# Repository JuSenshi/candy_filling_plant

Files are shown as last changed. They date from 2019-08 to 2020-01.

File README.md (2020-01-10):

# candy_filling_plant

# Projektbeschreibung
Das Fließbandsystem mit Abfüllanlage ist ein großer Bestandteil unseres gesamten Schulprojekts, der Automatisierung einer Bonbon - Abfüllanlage inkl. Lieferungslösung. Dieses Teilprojekt stellt den Prozess des Abfüllens der bestellten Bonbonbs bereit. Dies wird durch ein selbstkreiertes Fließband mit einem Schrittmotor, sowie einer Abfülllösung mit 3 Servomotoren erreicht. Desweiteren wird die Bestellung von einem RFID - Chip gelesen. Hierfür benutzen wir unter dem Fließband ein RFID - Lesegerät.

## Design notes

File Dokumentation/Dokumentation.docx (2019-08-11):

# Dokumentation - Bonbon Abfüllanlage

Elektrotechnik

# 1. Bauteil – Liste

## 1.1. Boards

Boardbezeichnung | Beschreibung
Arduino Uno R3 (A1) | Modul Abfüllung | Modul Fließband
Arduino Uno R3 (A2) | Modul Schließen
Motortreiber X113647 (X1) | Treiberplatine für Schrittmotor
RFID Modul MFRC-522 | RFID Modul zum Auslesen von Tags

## 1.2. Sensoren

Sensorbezeichnung | Beschreibung
B1: IR – Detektor (vgl. SFH 213 FA OSO) | IR Fotowiderstand für LS1
B2: IR – Detektor (vgl. SFH 213 FA OSO) | IR Fotowiderstand für LS2

## 1.3. Aktoren

Aktorbezeichnung | Beschreibung
M1: Servomotor SG90 | Modul Abfüllung | Abfüller Farbe Rot
M2: Servomotor SG90 | Modul Abfüllung | Abfüller Farbe Blau
M3: Servomotor SG90 | Modul Abfüllung | Abfüller Farbe Grün
M4: Servomotor SG90 | Modul Schließen | Schließer Oben
M5: Servomotor SG90 | Modul Schließen | Schließer Unten
M6: Schrittmotor 28BYJ-48 | Modul Fließband | Antrieb Fließband
LED1: IR – LED (vgl. IR 333-H0L10 EVL) | LED für Lichtschranke LS1
LED2: IR – LED (vgl. IR 333-H0L10 EVL) | LED für Lichtschranke LS2

## 1.4. Widerstände

Widerstandsbezeichnung | Beschreibung
R1: 220 Ω | 5% | 250mW | Vorwiderstand LED1 (LS1)
R2: 1k Ω | 5% | 250mW | Vorwiderstand B1 (LS1)
R3: 220 Ω | 5% | 250mW | Vorwiderstand LED2 (LS2)
R4: 1k Ω | 5% | 250mW | Vorwiderstand B2 (LS2)

# 2. Pin – Zuordnungen

## 1.1. Arduino A1 → Motortreiber X1

Pin – Arduino A1 | Pin – Motortreiber X1
2 | IN1 (A)
3 | IN2 (B)
4 | IN3 (C)
5 | IN4 (D)
5V | +
GND | -

## 1.2. Arduino A1 → Sensoren | Aktoren

Pin – Arduino A1 | Pin – Sensoren
6 | M1 (gelber Kontakt)
7 | M2 (gelber Kontakt)
8 | M3 (gelber Kontakt)
A0 | A2: A5
A5 | B1: Anode

## 1.3. Arduino A1 → RFID Modul

Pin – Arduino A1 | Pin – RFID Modul
9 | RST
10 | SDA
11 | MOSI
12 | MISO
13 | SCK
3,3V | 3,3V
GND | GND

## 1.4. Arduino A2 → Sonstige

Pin – Arduino A2 | Pin – Sonstige
2 | M4 (gelber Kontakt)
3 | M5 (gelber Kontakt)
A0 | B2: Anode
A5 | A1: A0

# 3. Schaltplan

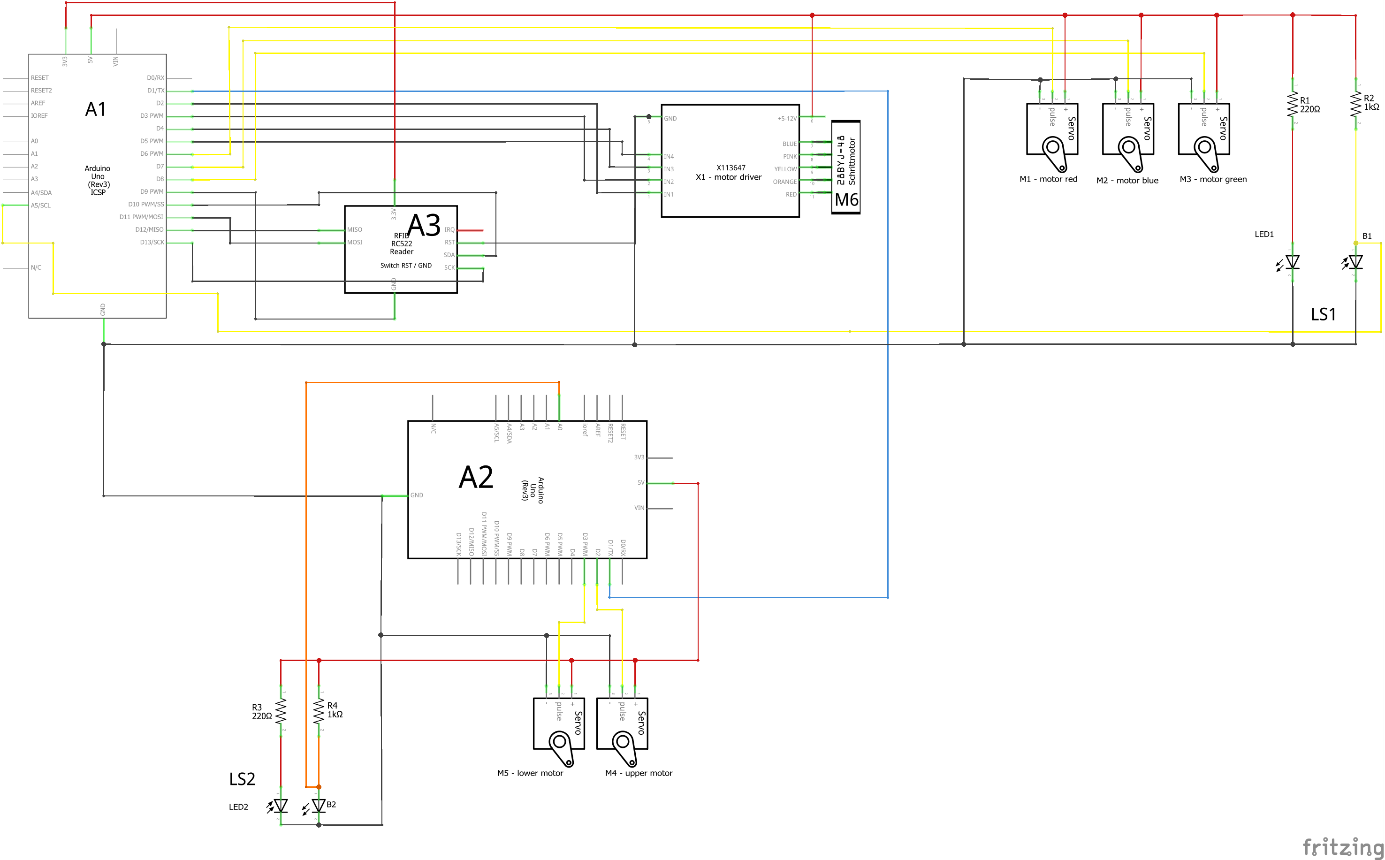
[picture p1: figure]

Bild online aufrufen (https://krieger-blog.de/wp-content/uploads/2019/08/circuit-board-schmetic-1024x636.png)

# 4. Steckplatinenansicht

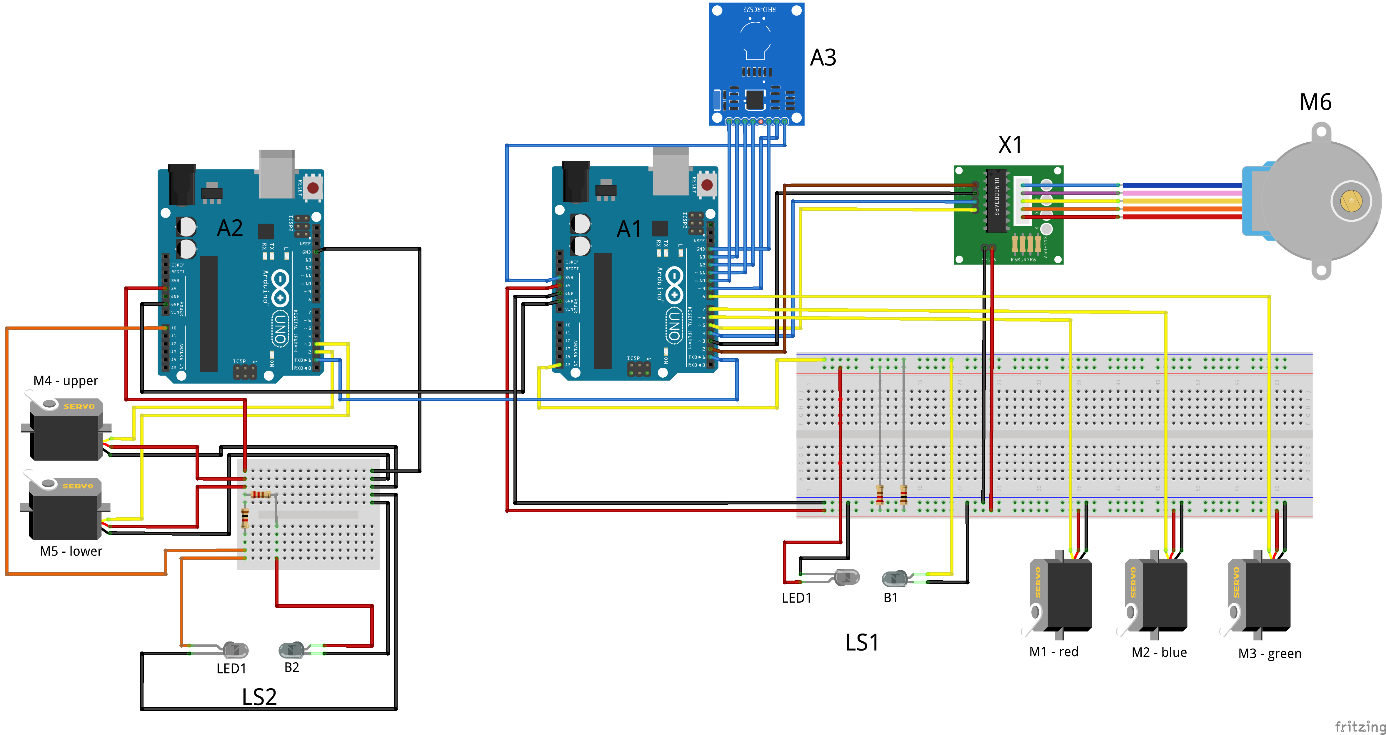
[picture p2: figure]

Bild online aufrufen (https://krieger-blog.de/wp-content/uploads/2019/08/schmetic-1024x543.png)

# 5. Programmcode

Die Programmcodes für beide Arduino Controller sind unter folgendem Link einsehbar und herunterladbar.

Github: Candy Filling Plant (https://github.com/KriegersBlog/candy_filling_plant)

Julian Krieger 11.08.2019 1 von 4

Dokumentation - Bonbon Abfüllanlage

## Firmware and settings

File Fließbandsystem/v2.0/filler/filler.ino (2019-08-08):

#include <SPI.h>                           // Integrates the SPI library for RFID pin support
#include <MFRC522.h>                       // Integrates RFID library for 15.44MHz NFC support
#define SS_PIN 10                          // Pin definition for the RFID library
#define RST_PIN 9                          // Pin definition for the RFID library
MFRC522 mfrc522(SS_PIN, RST_PIN);          // Applys given pins to library
MFRC522::MIFARE_Key key; // access key


uint8_t dataSize = 18;  //Size of all needed data in bytes: commandbyte + addressbyte + 16 data bytes | Anmerkung: Stimmt net
byte trailerBlock = 7;    // the trailer block that holds our security data (used for blocks 4/5/6)


const int L1 = 4; // IN3
const int L2 = 2; // IN1
const int L3 = 5; // IN4
const int L4 = 3; // IN2
const int motor[4] = {0b00000101, 0b00001001, 0b00001010, 0b00000110};
const int box_length = 1600;
const int red_motor = 6;
const int blue_motor = 7;
const int green_motor = 8;

void setup() {
  pinMode(L1, OUTPUT);
  pinMode(L2, OUTPUT);
  pinMode(L3, OUTPUT);
  pinMode(L4, OUTPUT);

  pinMode(red_motor, OUTPUT);
  pinMode(blue_motor, OUTPUT);
  pinMode(green_motor, OUTPUT);
  servo_move(30, red_motor, 100);
  servo_move(50, blue_motor, 100);
  servo_move(0, green_motor, 100);
  SPI.begin();
  mfrc522.PCD_Init();
}

void loop() {
  while (digitalRead(A0) == HIGH) {
    //Nüscht
  }
  if (analogRead(A5) < 900) {
    forward();
  }
  else {
    delay(100);
    mfrc522.PCD_Init();     // Initializes library for the RFID modul
    delay(100);
    
    for (byte i = 0; i < MFRC522::MF_KEY_SIZE; i++) {       //For key size:
      key.keyByte[i] = 0xFF;                                //Type key as OxFF
    }
    if (mfrc522.PICC_IsNewCardPresent()) {
      mfrc522.PICC_ReadCardSerial();
      mfrc522.PCD_Authenticate
      (MFRC522::PICC_CMD_MF_AUTH_KEY_A, trailerBlock, &key, &(mfrc522.uid));

      char chipInput_block4[16];                    //Array for information on block 4
      char chipInput_block5[16];                    //Array for information on block 5

      mfrc522.MIFARE_Read(4, chipInput_block4, &dataSize);
      mfrc522.MIFARE_Read(5, chipInput_block5, &dataSize);
      //Sector 4: 5, 13 | Sector 5: 7

      int bonbons = chipInput_block4[5] - 0x30;   //New int variable that is the size of the wanted bonbonbs
      for (int i = 0; i < bonbons; i++) {         //For number of bonbonbs
        servo_move(0, red_motor, 100);
        delay(100);
        servo_move(30, red_motor, 100);
        delay(100);
      }

      bonbons = chipInput_block4[13] - 0x30;    //Variable is number of wanted bonbons
      for (int i = 0; i < bonbons; i++) {
        servo_move(0, blue_motor, 100);
        delay(100);
        servo_move(50, blue_motor, 100);
        delay(100);
      }

      bonbons = chipInput_block5[7] - 0x30;
      for (int i = 0; i < bonbons; i++) {
        servo_move(50, green_motor, 100);
        delay(100);
        servo_move(0, green_motor, 100);
        delay(100);
      }

      while (analogRead(A5) > 900) {
        forward();
      }
    }
  }
}



void stepper(uint8_t value) {
  digitalWrite(L1, value & 0b00000001);
  digitalWrite(L2, value & 0b00000010);
  digitalWrite(L3, value & 0b00000100);
  digitalWrite(L4, value & 0b00001000);
}

void forward() {
  for (int i = 0; i < 4; i++) {
    stepper(motor[i]);
    delay(2);
  }
}

void backward() {
  for (int x = 3; x >= 0; x--) {
    stepper(motor[x]);
    delay(2);
  }
}


void servo_move(byte angle_degree, uint8_t motor_pin, byte repeater){

    pinMode(motor_pin, OUTPUT);                       //Declares given pin of the servo as output
    int time = (angle_degree/180.0 * 1925) + 425;     //Calculates degree time for a SV-90
    int delaytime = 20000-time;
    for(int i = 0; i<repeater; i++){
      digitalWrite(motor_pin, HIGH);
      delayMicroseconds(time);
      digitalWrite(motor_pin, LOW);
      delayMicroseconds(delaytime);
    }
}

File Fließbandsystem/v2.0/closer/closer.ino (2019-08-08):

/* 
 *  This code is essential for the clsoing mechanism. 
 * Copyright by Julian Krieger, Dennis Domagala, Pascal Gläß
 */


const int top_motor = 2;
const int bottom_motor = 3;

void setup() {
  pinMode(2, OUTPUT);
  pinMode(3, OUTPUT);
  pinMode(A5, OUTPUT);
  pinMode(A0, INPUT);
  servo_move(20, top_motor, 100);    // Ausgangsstellung
  servo_move(20, bottom_motor, 100);    // Ausgangsstellung
}

void loop() {
if (analogRead(A0) > 600){
  digitalWrite(A5, HIGH);
  schliessen();
  delay(100);
  digitalWrite(A5, LOW);
  while(analogRead(A0) > 600);
  }
}

void schliessen(){

  servo_move(150, top_motor, 100);   // Top Servo runter
  delay(500);
  servo_move(20, top_motor, 100);    // Top Servo zurück
  delay(500);
  servo_move(60, bottom_motor, 100);   // Side Servo runter
  delay(500);
  servo_move(20, bottom_motor, 100);    // Side Servo hoch
}


void servo_move(byte angle_degree, uint8_t motor_pin, byte repeater){

    pinMode(motor_pin, OUTPUT);                       //Declares given pin of the servo as output
    int time = (angle_degree/180.0 * 1925) + 425;     //Calculates degree time for a SV-90
    int delaytime = 20000-time;
    for(int i = 0; i<repeater; i++){
      digitalWrite(motor_pin, HIGH);
      delayMicroseconds(time);
      digitalWrite(motor_pin, LOW);
      delayMicroseconds(delaytime);
    }
}

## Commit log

2019-08-11 New Documentation
    [project.fzz]
2020-01-10 Final Commit
    [Fliessband.fzz, Schaltplan.fzz]
